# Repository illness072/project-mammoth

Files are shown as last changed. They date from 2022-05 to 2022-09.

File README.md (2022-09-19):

# Project 🦣

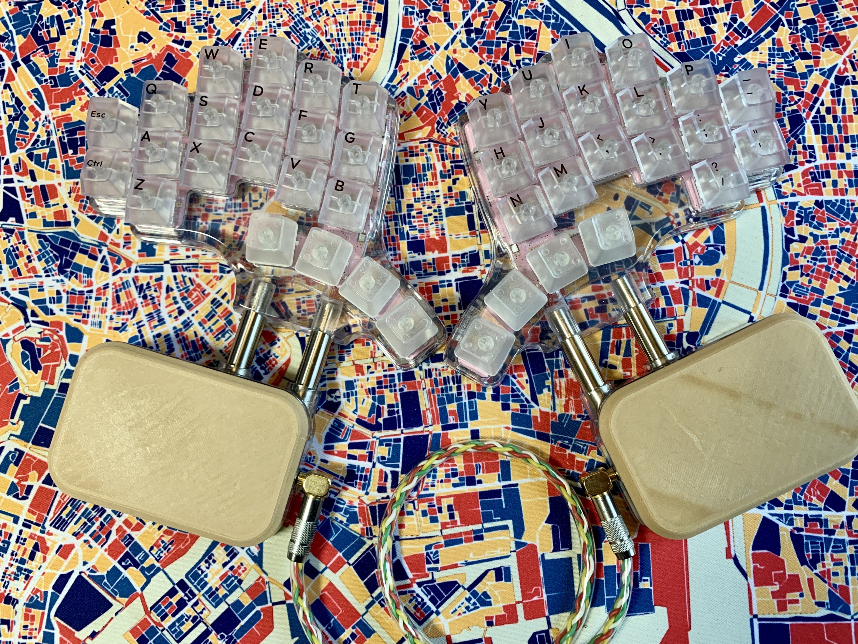
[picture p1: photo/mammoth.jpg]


This keyboard was developed as a successor to the elephant42 and was originally planned to be released as mammoth42. However, during the development process, custom keyboards by other authors, Mammoth75 and Mammoth20, were released, and it seemed somewhat awkward to re-release the keyboard under the same name.
However, we could not give up our desire to use 🦣 as a companion to 🐘, so we decided to give it this name, taking care not to infringe on their names as much as possible.

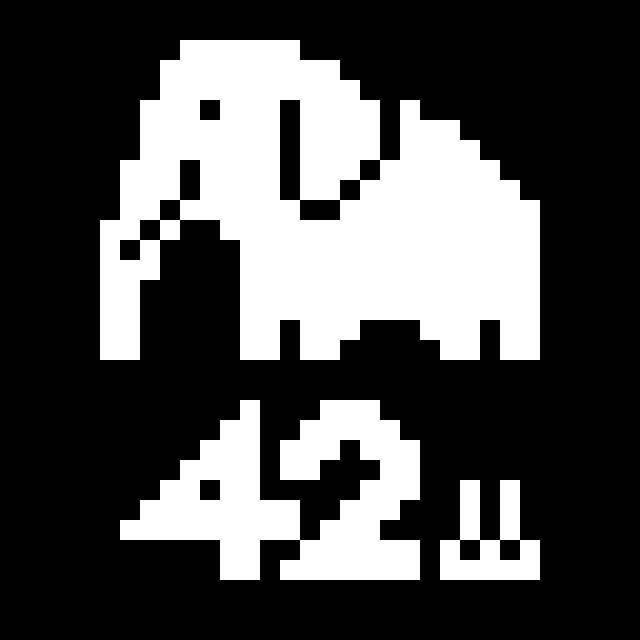
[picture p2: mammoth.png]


# Still WIP, or Forever WIP?

This project is still in its infancy and is only about 20% of the way to the final product I have in mind. There are still a lot of unresolved bugs and issues, but even at this point, I think the keyboard is fun enough to use. Let's enjoy "being unfinished" together.

## Rough Milestones

1. [x] Works as USB HID with Pro Micro or as BLE HID with ISP1807micro and CR2032 battery.
1. [x] Operation as a left and right independent BLE device. The board might be modified to use Seeed XIAO BLE and the batteries might be modified to use NiMH rechargeable batteries.
1. [ ] Support for 34mm trackball.
1. (Still a secret.)

    :

## To be confirmed before manufacturing

The design currently uses two MCP23017-E/SS. These I/O expanders have long since been depleted from the market due to the recent semiconductor shortage and are currently priced at two to three times the normal price. To protect your wallet, it would be wise to wait for the stock to come back.

# BOM

## Main Boards

|Ref|Qty|Value or Part|Description|
|--|--|--|--|
||42|1N4148W|Fast Switching Diode|
||42|CPG151101S11-16|Kailh Switch Socket|
|U1,U2|2|MCP23017-E/SS|16-Bit I/O Expander|
||2|BM05B-ACHSS-A-GAN-ETF(LF)(SN)|JST ACH Connector 5P|

## Palm-rest Boards

|Ref|Qty|Value or Part|Description|
|--|--|--|--|
||2|BH-411-4P24|AAA Battery Holder|
||2|BM05B-ACHSS-A-GAN-ETF(LF)(SN)|JST ACH Connector 5P|
||2|SS-12D00G3|Slide Switch|
||2|Seeed Studio XIAO nRF52840||
|L1|2|100μH|Inductor|
|R1,R2|4|4.6kΩ|Resistor|
|C1|2|47μF|Capacitor|
|C2|2|22μF|Capacitor|
|D1|2|1S4|Schotky barrier diode|
|HT7733A|2|HT7733A|PFM Step-up DC/DC Converter|
|TRRS|0|MJ-4PP-9|TRRS Jack (Optional:2)|

## Cables

|Qty|Value or Part|Description|
|--|--|--|
|4|ACHR-05V-A-S|JST ACH Connector Housing 5P|
|10|01SACHSACH-30L-150|JST ACH Connector Contact(SACH-003G-P0.2) Cable|

# Where's the firmware?

Not yet.

# License?

Beerware!!

Come drink beer in Tokyo with me!! 🍺🍺🍺

# Poor English?

Sorry, it's DeepL Translate.

# [PR] Sponsored by PCBWay

Project 🦣 is currently prototyping with support from PCBWay (https://www.pcbway.com/).
We found the silks to be more accurate and beautiful than those of various PCB makers in the same price range.

If you are in doubt about which PCB manufacturer to manufacture, PCBWay, with its experience in manufacturing 🦣, may be a good choice.

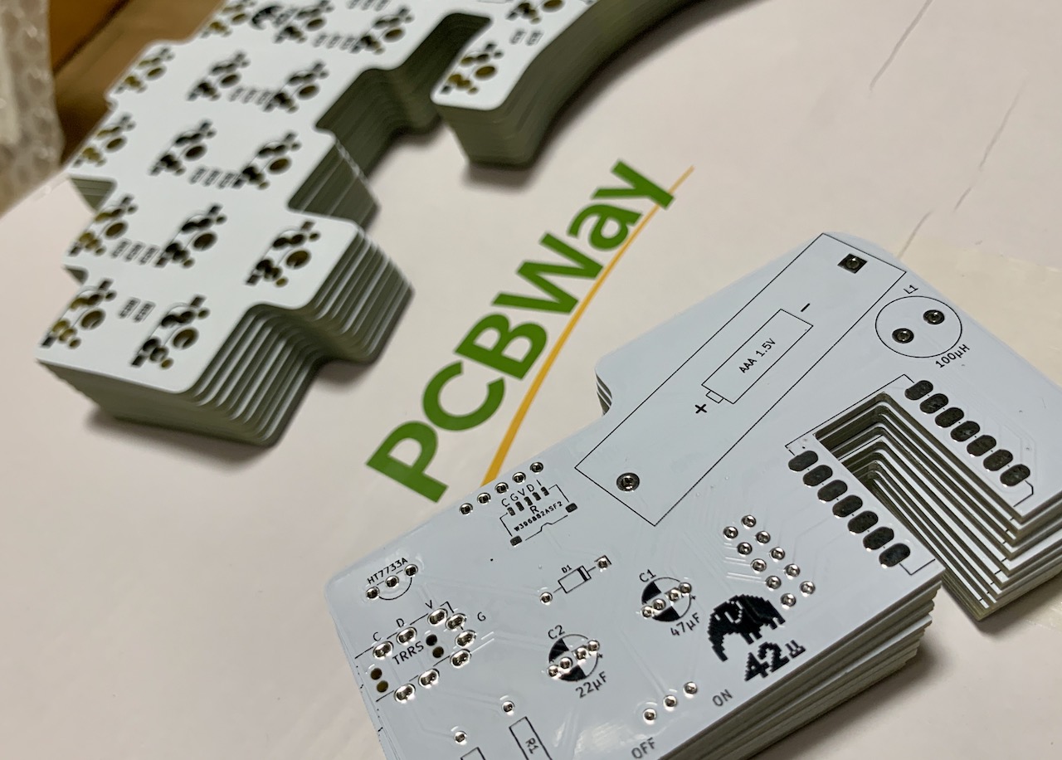
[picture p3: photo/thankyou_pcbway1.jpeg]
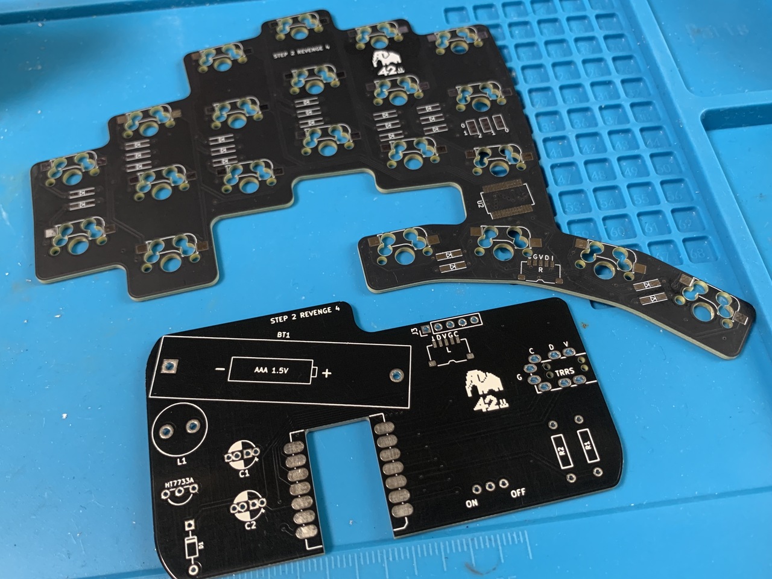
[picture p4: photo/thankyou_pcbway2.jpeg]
 

Thanks a lot PCBWay!

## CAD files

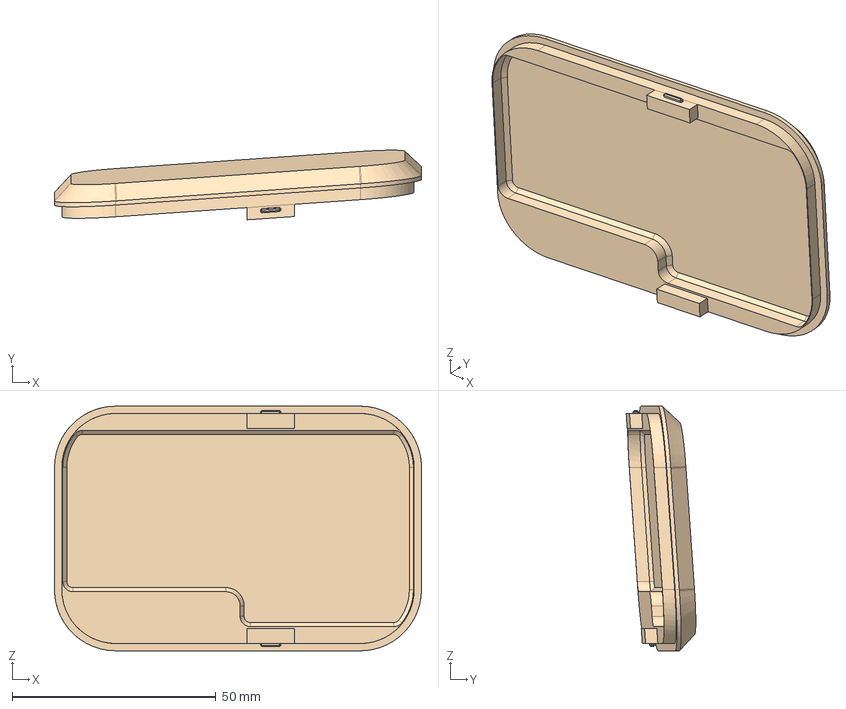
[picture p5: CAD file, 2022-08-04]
models/step/palm-RT.step
90.0 x 17.1 x 60.0 mm

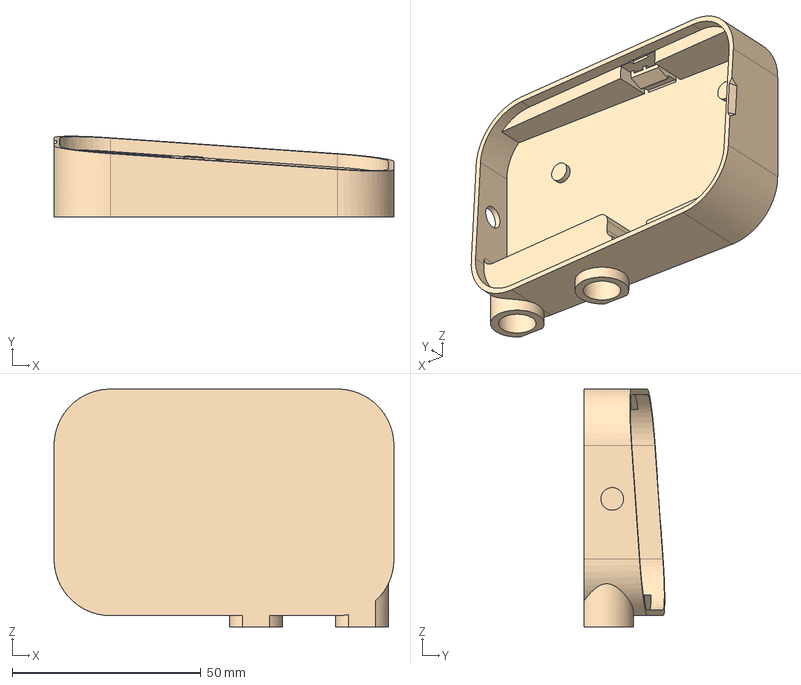
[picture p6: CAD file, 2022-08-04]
models/step/palm-LB.step
90.0 x 21.4 x 63.0 mm

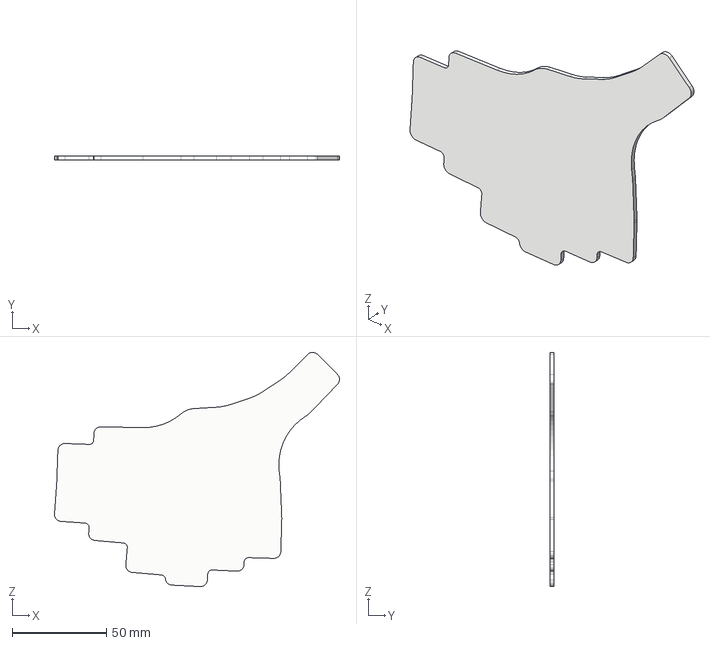
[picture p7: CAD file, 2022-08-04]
models/step/case-B.step
151.6 x 2.00 x 124.5 mm

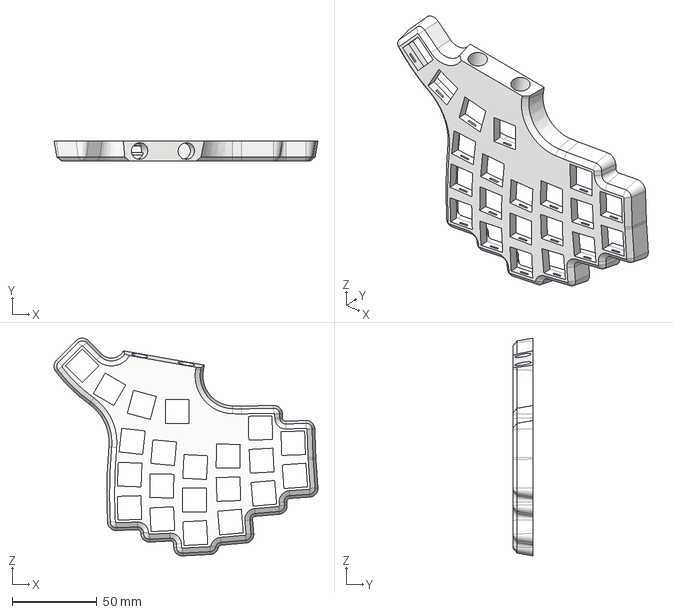
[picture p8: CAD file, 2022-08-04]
models/step/case-L.step
155.9 x 12.0 x 128.6 mm

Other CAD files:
models/step/palm-LT.step
models/step/palm-RB.step
models/step/case-R.step
models/dxf/case-B.dxf
models/stl/case-B.stl
models/stl/case-L.stl
models/stl/case-R.stl
models/stl/palm-LT.stl
models/stl/palm-RB.stl
models/stl/palm-RT.stl
models/stl/palm_LB.stl

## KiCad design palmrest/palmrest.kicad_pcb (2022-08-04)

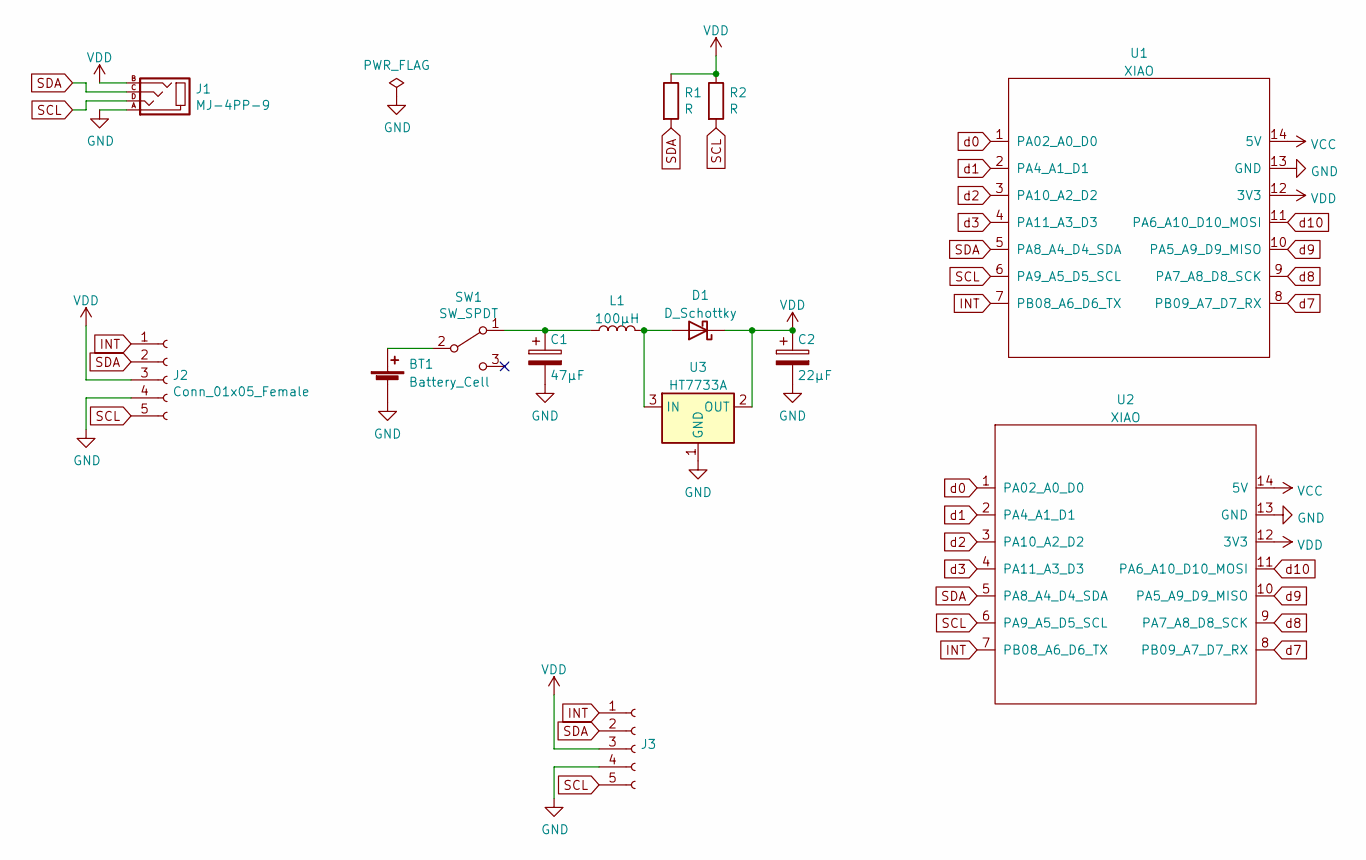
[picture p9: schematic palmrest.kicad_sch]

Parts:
BT1: Battery_Cell; bat_case_AAA
C1: 47μF; CP_Radial_D5.0mm_P2.00mm_P5.00mm_rev
C2: 22μF; CP_Radial_D5.0mm_P2.00mm_P5.00mm_rev
D1: D_Schottky; D_DO-34_SOD68_P7.62mm_Horizontal
J1: MJ-4PP-9
J2: Conn_01x05_Female; JST_ACH_BM05B-ACHSS-A-GAN-ETF_1x05-1MP_P1.20mm_Vertical_rev
J3: (no value)
L1: 100μH; L_Radial_D10.0mm_P5.00mm_Fastron_07M
R1, R2: R
SW1: SW_SPDT; SS-12D00G3
U1, U2: XIAO; Seeeduino XIAO-MOUDLE14P-2.54-21X17.8MM
U3: HT7733A

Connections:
GND: BT1.2 (-), C1.2, C2.2, J1.A, J2.4, J3.4, U1.13 (GND), U2.13 (GND), U3.1 (GND)
INT: J2.1, J3.1, U1.7 (PB08_A6_D6_TX), U2.7 (PB08_A6_D6_TX)
unnamed: BT1.1 (+), SW1.2 (B)
unnamed: C1.1, L1.1, SW1.1 (A)
unnamed: D1.2 (A), L1.2, U3.3 (IN)
SCL: J1.D, J2.5, J3.5, R2.2, U1.6 (PA9_A5_D5_SCL), U2.6 (PA9_A5_D5_SCL)
SDA: J1.C, J2.2, J3.2, R1.2, U1.5 (PA8_A4_D4_SDA), U2.5 (PA8_A4_D4_SDA)
VCC: U1.14 (5V), U2.14 (5V)
VDD: C2.1, D1.1 (K), J1.B, J2.3, J3.3, R1.1, R2.1, U1.12 (3V3), U2.12 (3V3), U3.2 (OUT)
d0: U1.1 (PA02_A0_D0), U2.1 (PA02_A0_D0)
d1: U1.2 (PA4_A1_D1), U2.2 (PA4_A1_D1)
d2: U1.3 (PA10_A2_D2), U2.3 (PA10_A2_D2)
d3: U1.4 (PA11_A3_D3), U2.4 (PA11_A3_D3)
d7: U1.8 (PB09_A7_D7_RX), U2.8 (PB09_A7_D7_RX)
d8: U1.9 (PA7_A8_D8_SCK), U2.9 (PA7_A8_D8_SCK)
d9: U1.10 (PA5_A9_D9_MISO), U2.10 (PA5_A9_D9_MISO)
d10: U1.11 (PA6_A10_D10_MOSI), U2.11 (PA6_A10_D10_MOSI)

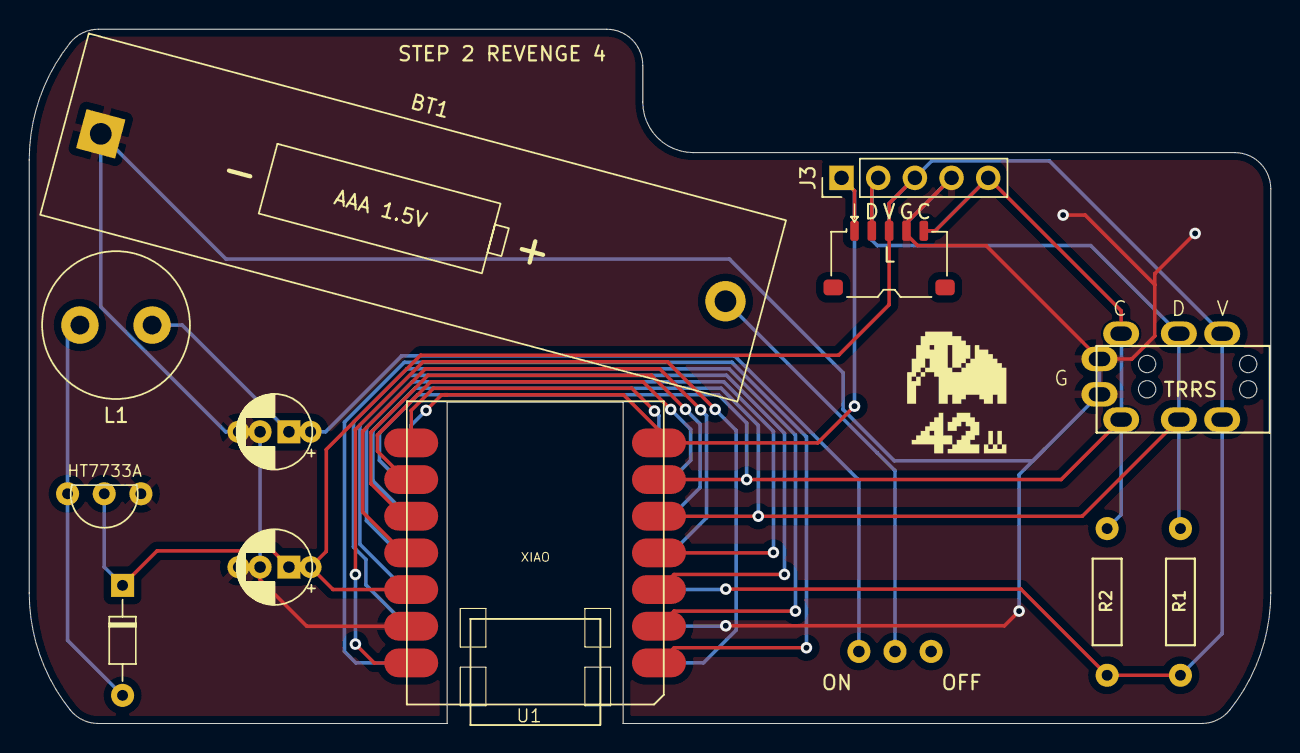
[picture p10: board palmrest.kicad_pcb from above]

Board: 2 copper layers, 86.0 x 48.1 mm, 14 parts (1 on the bottom side), 17 nets.

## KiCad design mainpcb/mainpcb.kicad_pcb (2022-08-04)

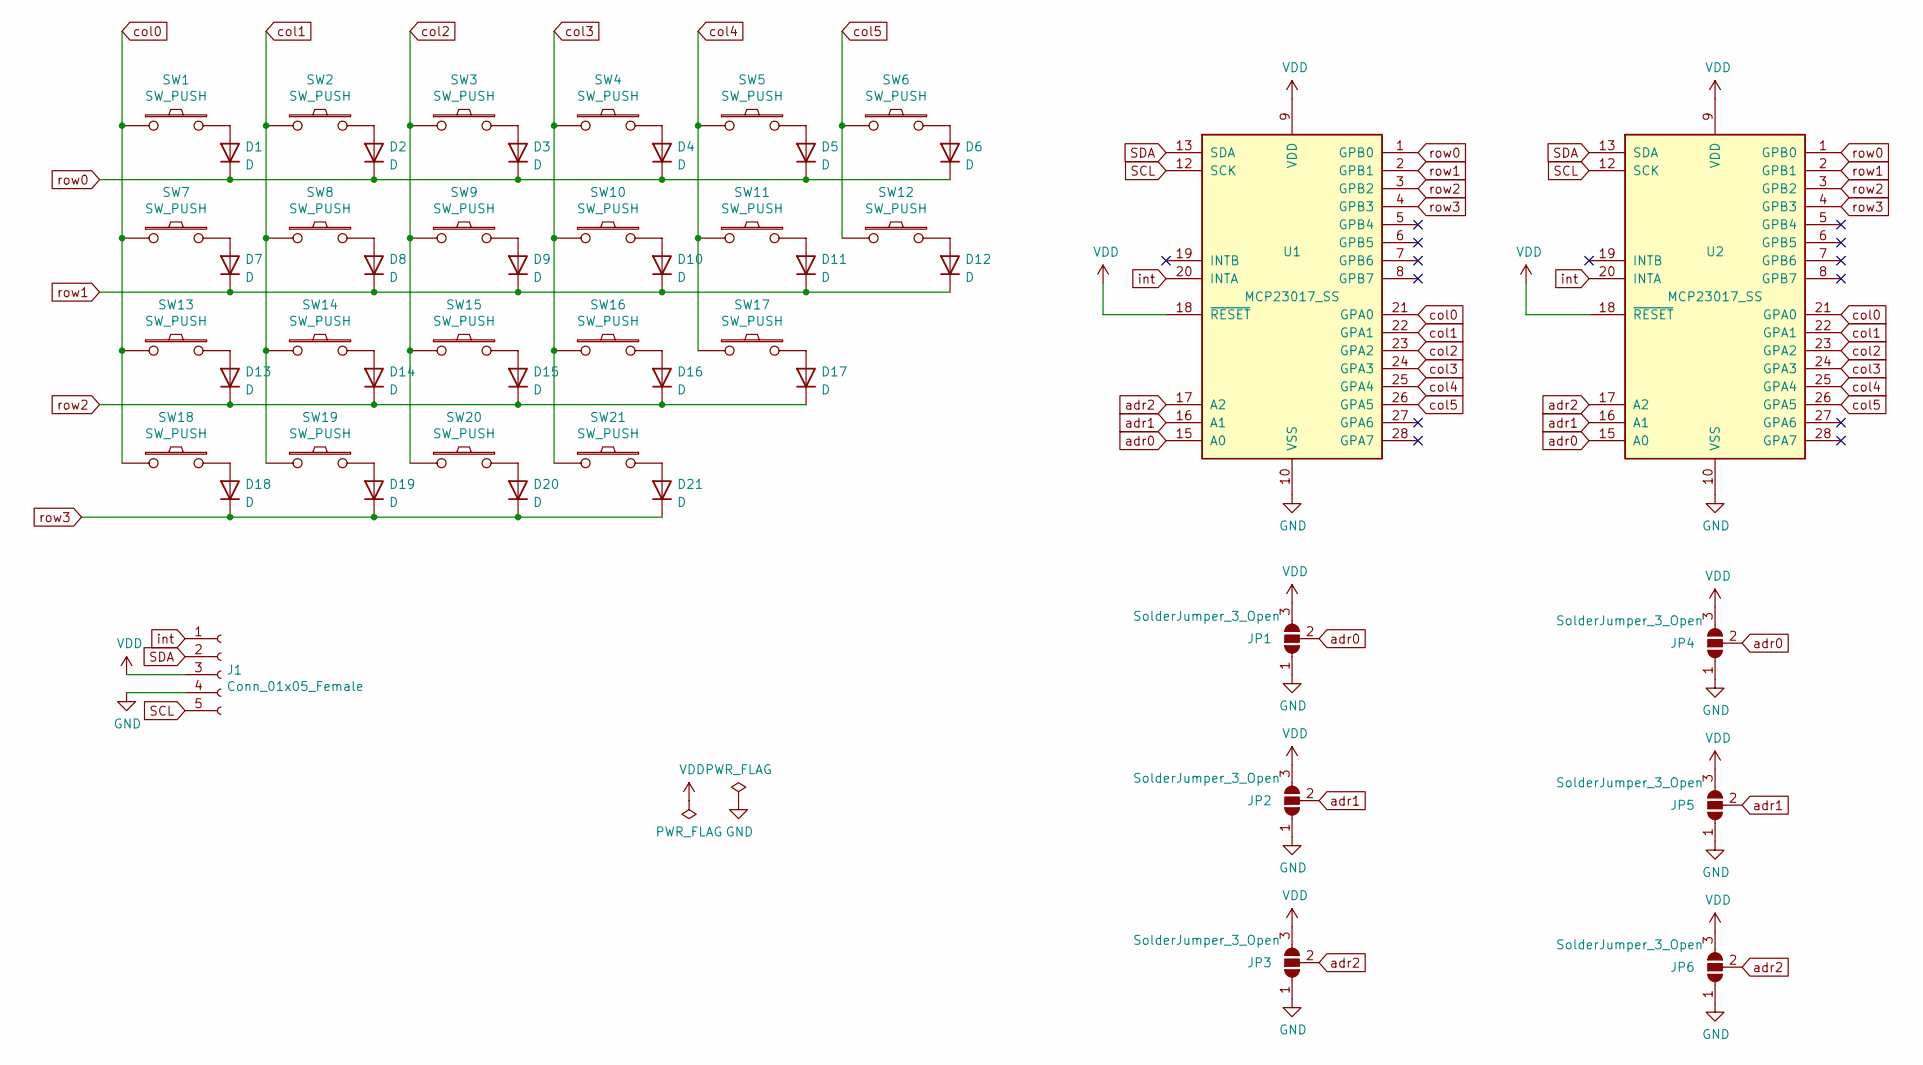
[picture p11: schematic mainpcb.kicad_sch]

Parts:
D1, D2, D3, D4, D5, D6, D7, D8, D9, D10, D11, D12, D13, D14, D15, D16, D17, D18, D19, D20, D21: D
J1: Conn_01x05_Female; JST_ACH_BM05B-ACHSS-A-GAN-ETF_1x05-1MP_P1.20mm_Vertical_rev
JP1, JP2, JP3, JP4, JP5, JP6: SolderJumper_3_Open; SolderJumper-3_P1.3mm_Open_Pad1.0x1.5mm
SW1, SW2, SW3, SW4, SW5, SW6, SW7, SW8, SW9, SW10, SW11, SW12, SW13, SW14, SW15, SW16, SW17, SW18, SW19, SW20, SW21: SW_PUSH; MX_Hotswap_R_1u
U1, U2: MCP23017_SS; SSOP-28_5.3x10.2mm_P0.65mm

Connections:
GND: J1.4, JP1.1 (A), JP2.1 (A), JP3.1 (A), JP4.1 (A), JP5.1 (A), JP6.1 (A), U1.10 (VSS), U2.10 (VSS)
unnamed: D1.2 (A), SW1.2
unnamed: D2.2 (A), SW2.2
unnamed: D3.2 (A), SW3.2
unnamed: D4.2 (A), SW4.2
unnamed: D5.2 (A), SW5.2
unnamed: D6.2 (A), SW6.2
unnamed: D7.2 (A), SW7.2
unnamed: D8.2 (A), SW8.2
unnamed: D9.2 (A), SW9.2
unnamed: D10.2 (A), SW10.2
unnamed: D11.2 (A), SW11.2
unnamed: D12.2 (A), SW12.2
unnamed: D13.2 (A), SW13.2
unnamed: D14.2 (A), SW14.2
unnamed: D15.2 (A), SW15.2
unnamed: D16.2 (A), SW16.2
unnamed: D17.2 (A), SW17.2
unnamed: D18.2 (A), SW18.2
unnamed: D19.2 (A), SW19.2
unnamed: D20.2 (A), SW20.2
unnamed: D21.2 (A), SW21.2
SCL: J1.5, U1.12 (SCK), U2.12 (SCK)
SDA: J1.2, U1.13 (SDA), U2.13 (SDA)
VDD: J1.3, JP1.3 (B), JP2.3 (B), JP3.3 (B), JP4.3 (B), JP5.3 (B), JP6.3 (B), U1.9 (VDD), U1.18 (~RESET), U2.9 (VDD), U2.18 (~RESET)
adr0: JP1.2 (C), JP4.2 (C), U1.15 (A0), U2.15 (A0)
adr1: JP2.2 (C), JP5.2 (C), U1.16 (A1), U2.16 (A1)
adr2: JP3.2 (C), JP6.2 (C), U1.17 (A2), U2.17 (A2)
col0: SW1.1, SW7.1, SW13.1, SW18.1, U1.21 (GPA0), U2.21 (GPA0)
col1: SW2.1, SW8.1, SW14.1, SW19.1, U1.22 (GPA1), U2.22 (GPA1)
col2: SW3.1, SW9.1, SW15.1, SW20.1, U1.23 (GPA2), U2.23 (GPA2)
col3: SW4.1, SW10.1, SW16.1, SW21.1, U1.24 (GPA3), U2.24 (GPA3)
col4: SW5.1, SW11.1, SW17.1, U1.25 (GPA4), U2.25 (GPA4)
col5: SW6.1, SW12.1, U1.26 (GPA5), U2.26 (GPA5)
int: J1.1, U1.20 (INTA), U2.20 (INTA)
row0: D1.1 (K), D2.1 (K), D3.1 (K), D4.1 (K), D5.1 (K), D6.1 (K), U1.1 (GPB0), U2.1 (GPB0)
row1: D7.1 (K), D8.1 (K), D9.1 (K), D10.1 (K), D11.1 (K), D12.1 (K), U1.2 (GPB1), U2.2 (GPB1)
row2: D13.1 (K), D14.1 (K), D15.1 (K), D16.1 (K), D17.1 (K), U1.3 (GPB2), U2.3 (GPB2)
row3: D18.1 (K), D19.1 (K), D20.1 (K), D21.1 (K), U1.4 (GPB3), U2.4 (GPB3)

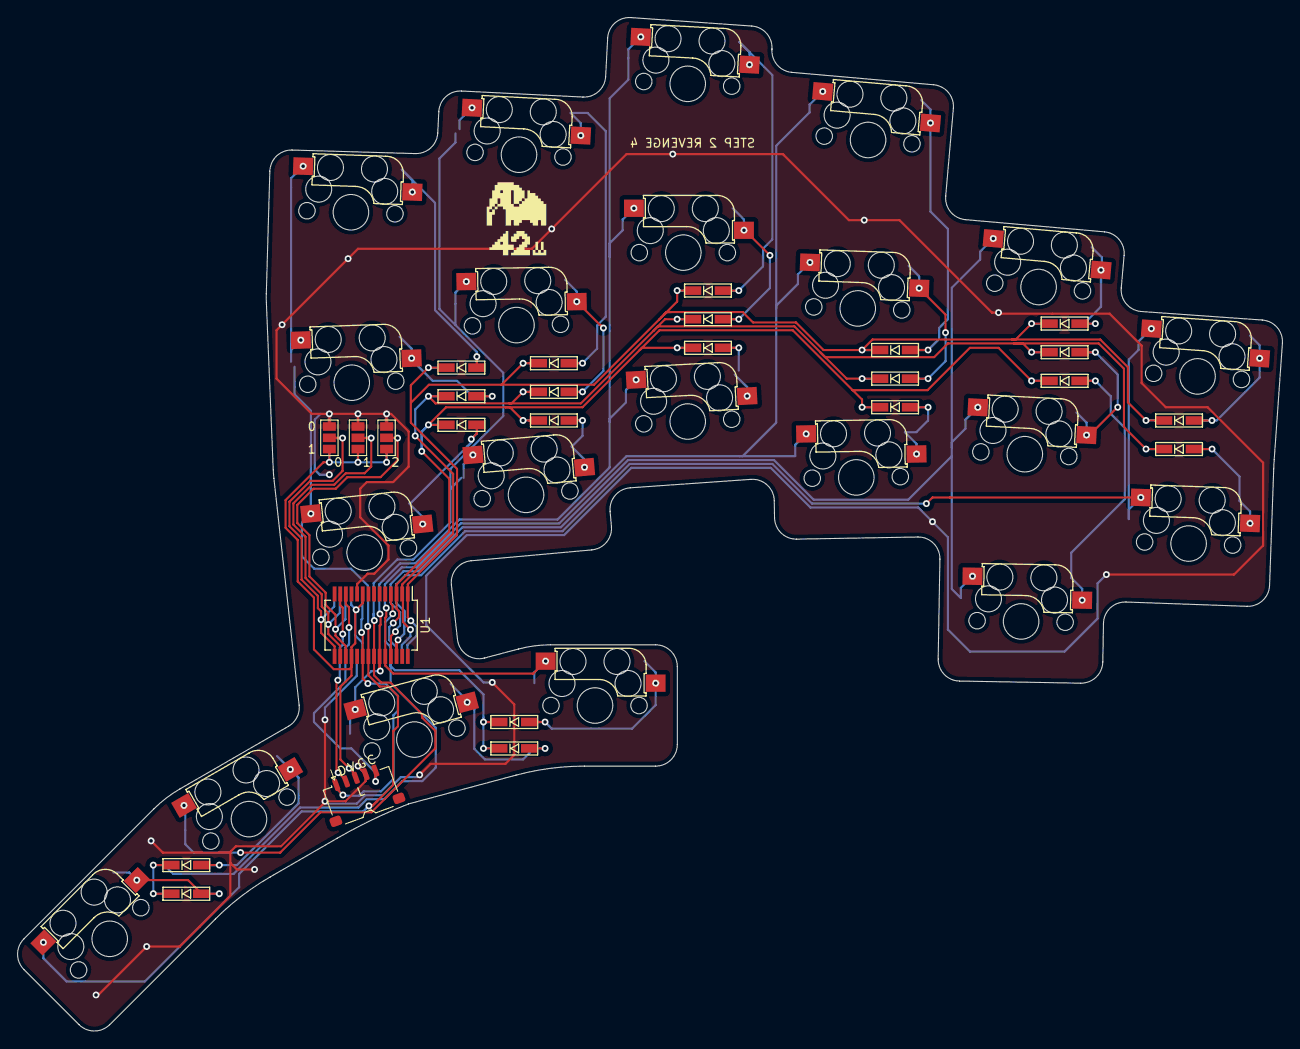
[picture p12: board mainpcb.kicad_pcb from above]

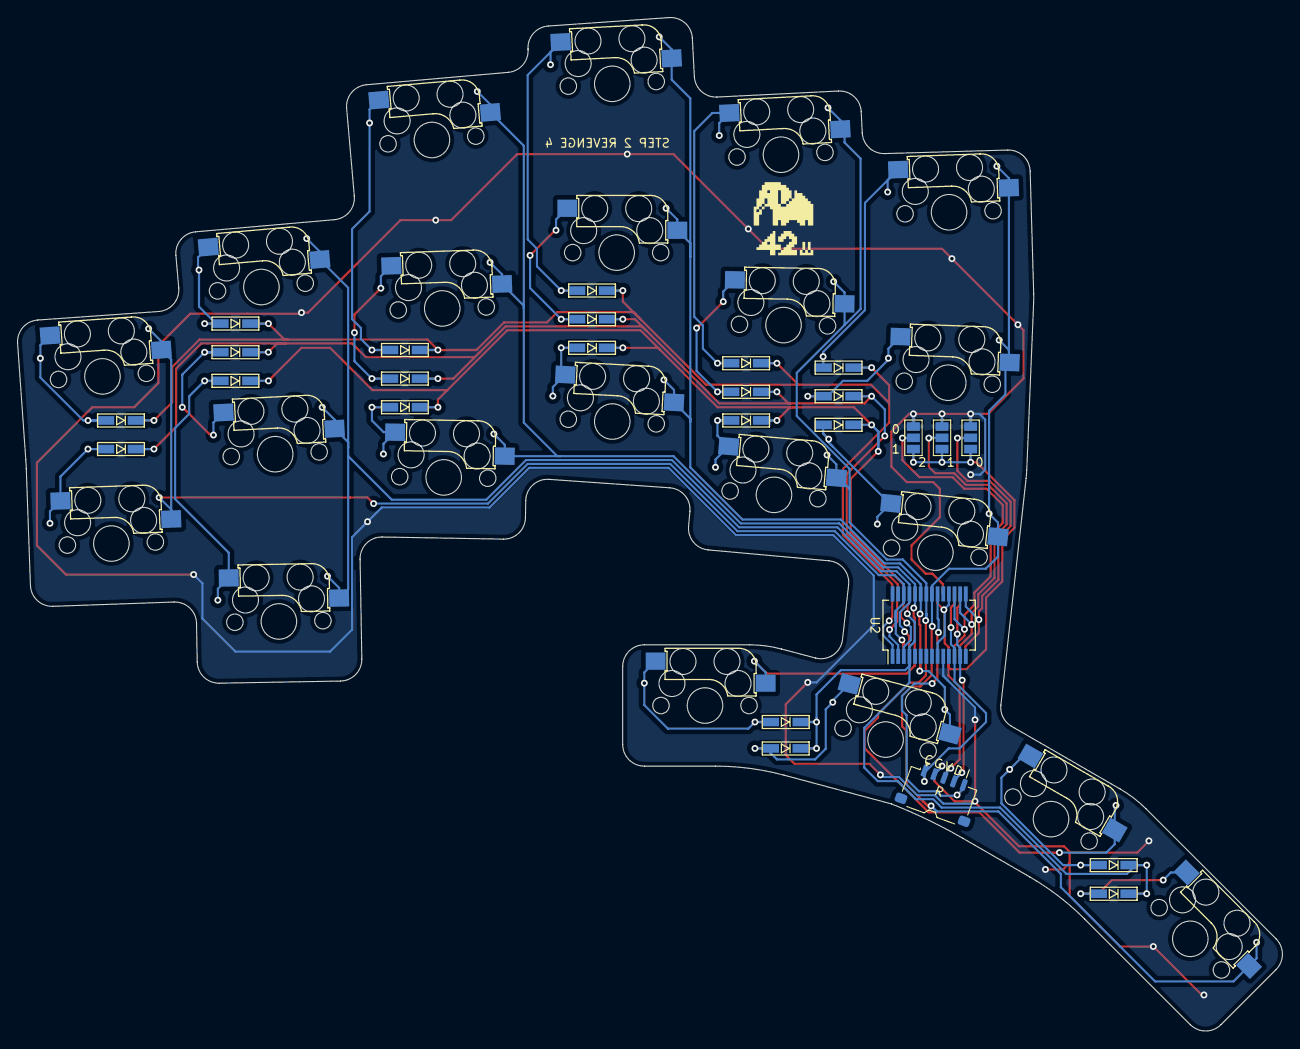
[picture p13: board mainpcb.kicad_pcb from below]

Board: 2 copper layers, 146.0 x 116.9 mm, 51 parts (4 on the bottom side), 39 nets.

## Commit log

2022-06-21 key-matrix using single mcp23017
    [mainpcb.kicad_pcb, mainpcb.kicad_sch]
2022-06-21 fix footprint
    [mainpcb.kicad_pcb, mainpcb.kicad_sch]
2022-06-21 remove private path
    [palmrest.kicad_pcb]
2022-07-19 revenge 4
    [mainpcb.kicad_pcb, mainpcb.kicad_sch, palmrest.kicad_pcb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]
2022-08-04 add gerber dir to gitignore
2022-08-04 update models
    [case-B.step, case-L.step, case-L.stl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]
2022-09-19 add BOM
